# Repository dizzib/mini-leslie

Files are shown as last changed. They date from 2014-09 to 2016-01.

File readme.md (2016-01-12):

# Mini-Leslie

To aim is to reproduce the behaviour of a traditional [Leslie cabinet][Leslie]
but in a much smaller space.

## Components

* [Brushed DC motor controller](./brushed-dc-motor)
* [Upper rotor and speaker](./upper-rotor)
* [Footswitch box](./footswitch)
* [Crossover (optional)](./crossover)

## License

[MIT](./LICENSE)

[Leslie]: https://en.wikipedia.org/wiki/Leslie_speaker

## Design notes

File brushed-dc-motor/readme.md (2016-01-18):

# Brushed DC motor controller

## Parts

* Arduino Nano (or similar)
* L298N motor driver board
* 24v/120w scooter DC motor (not recommended -- see [issue #1](https://github.com/dizzib/mini-leslie/issues/1))
* small breadboard
* jumper wires
* 1kOhm resistor x 2
* 6.35mm jack

## Circuit diagram

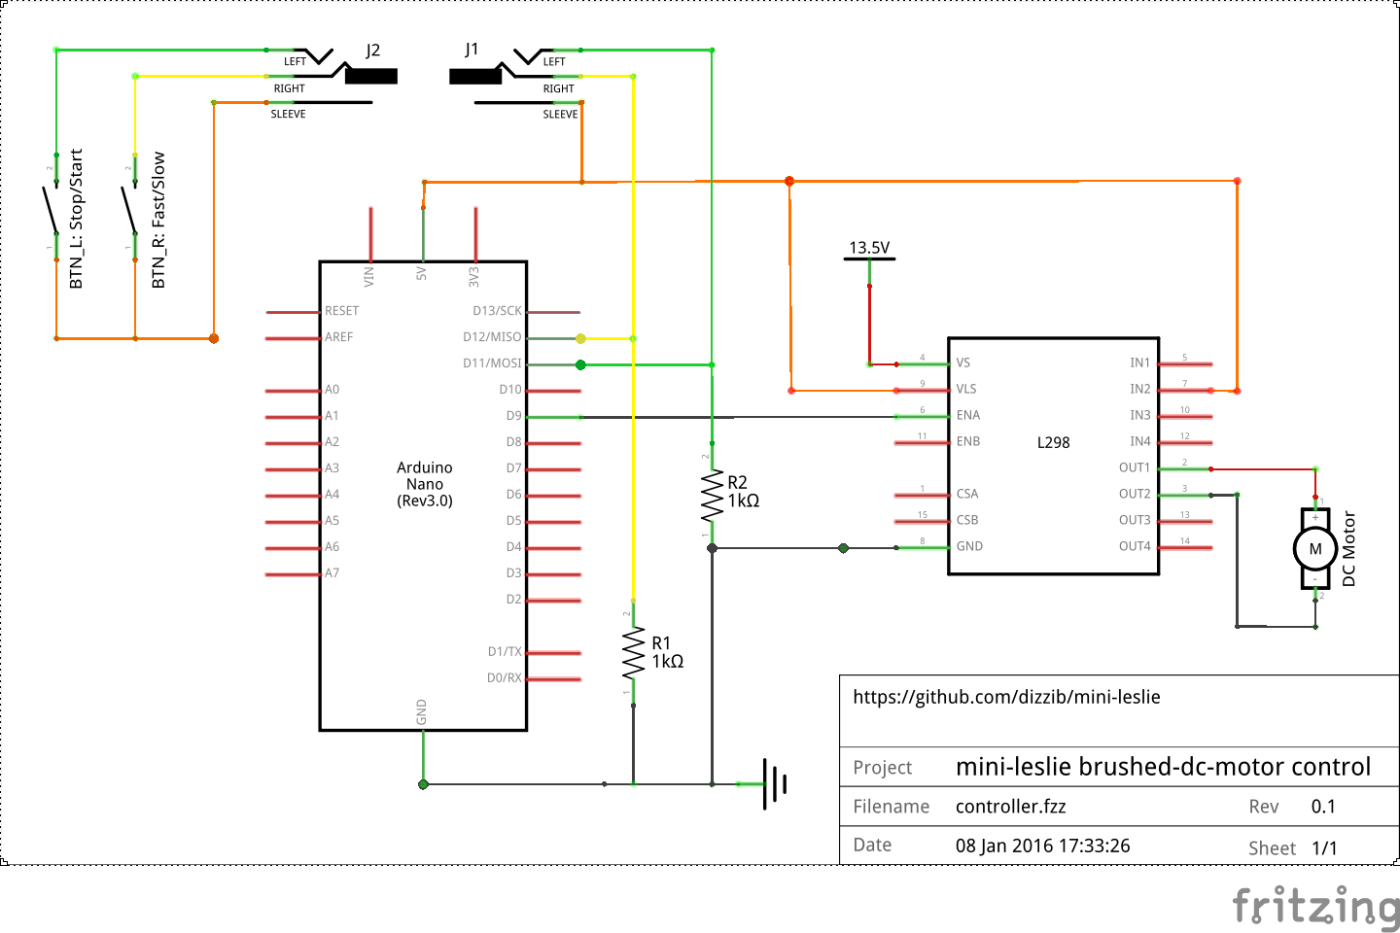
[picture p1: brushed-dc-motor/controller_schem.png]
schematic


## Notes

I'm using a 60-watt 5-amp switching power supply whose voltage options include 9/12/13.5/15v and
I've discovered 13.5v works best but YMMV.

This setup draws less than 20 watts at high speed, so I'd think both the motor
and power supply could be downsized to reduce noise and vibration.

## Pictures

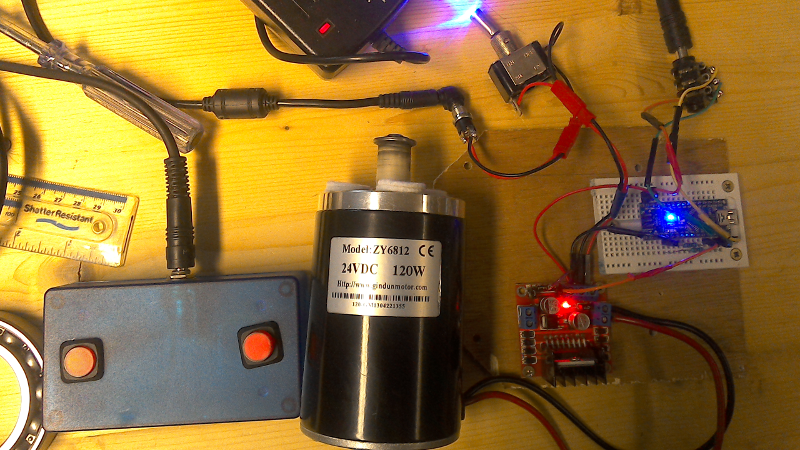
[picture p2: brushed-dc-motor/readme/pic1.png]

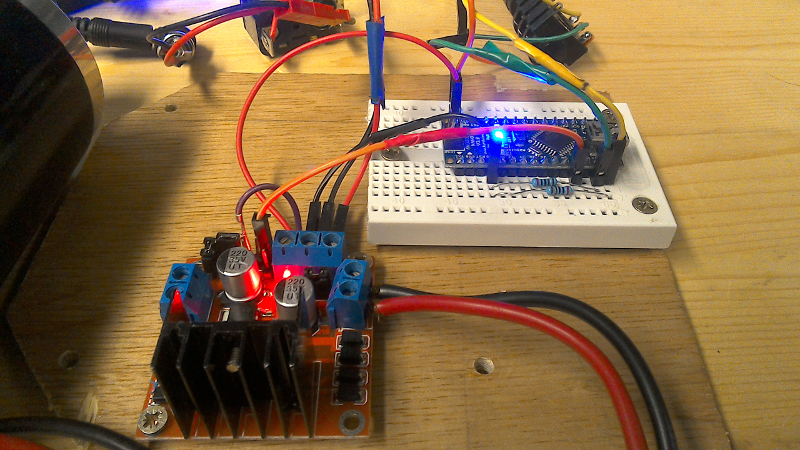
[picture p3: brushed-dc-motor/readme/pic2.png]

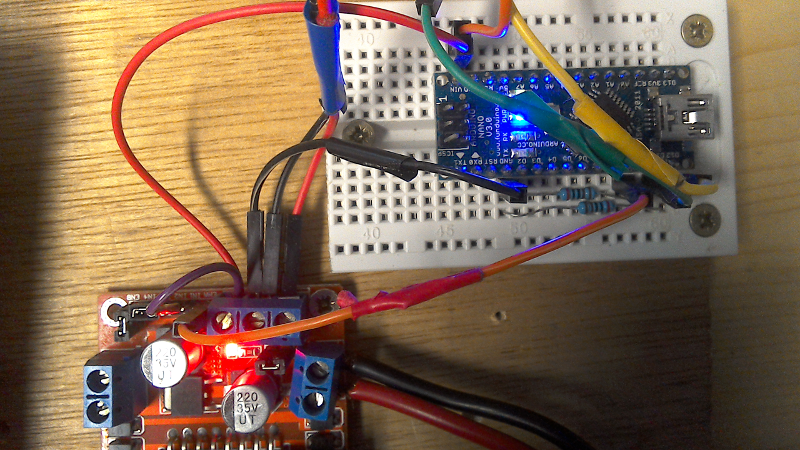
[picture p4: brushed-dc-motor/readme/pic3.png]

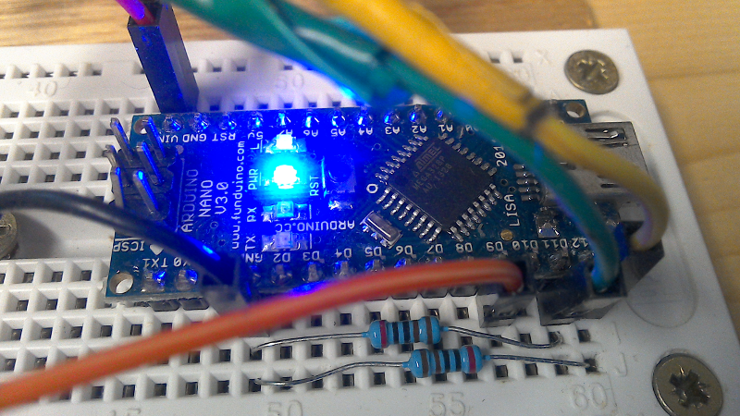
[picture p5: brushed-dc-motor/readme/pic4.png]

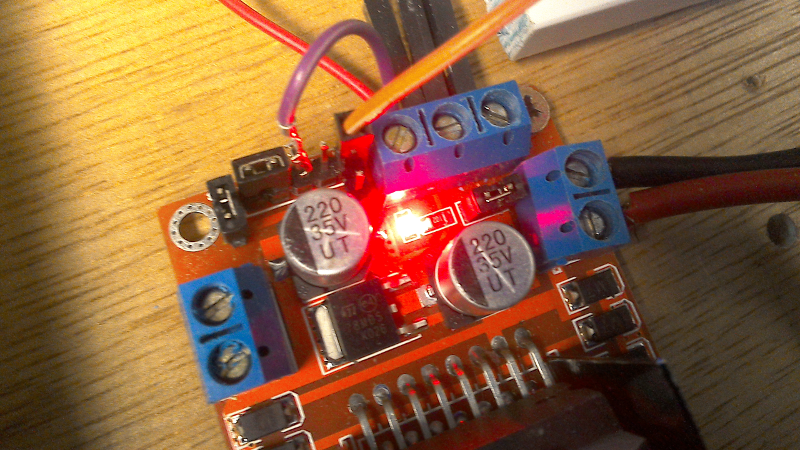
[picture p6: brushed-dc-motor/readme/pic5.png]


## Videos

[Arduino + Motor Test](https://www.youtube.com/watch?v=1-SFwXpB4cE)

[Hammond M3 Demo](https://www.youtube.com/watch?v=sb72E83Was0)

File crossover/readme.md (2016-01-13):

# Mini Crossover

Whereas an original Leslie 122 drives two 16-ohm speakers, this mini crossover is
designed to drive two 8-ohm speakers.

This is a accomplished by doubling the original capacitor values (7.8uF, 12.5uF)
and halving the original inductor values (3.2mH, 5.2mH).

## Parts

* small box 17cm x 9cm x 5.5cm
* 6.35mm jack x 3 (1 in, 2 outs)
* 15.6uF capacitor
* 25uF capacitor
* 1.6mH inductor
* 2.6mH inductor

## Circuit diagram

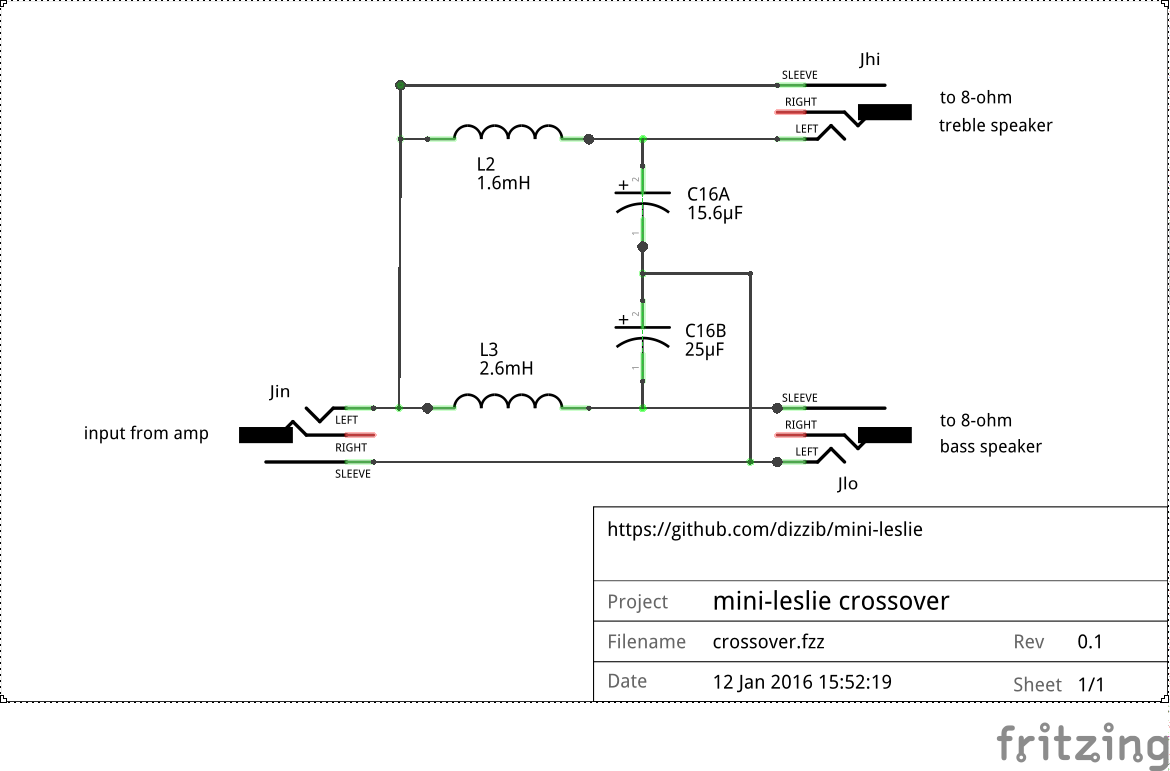
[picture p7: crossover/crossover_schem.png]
schematic


## Modifications

Since my bass speaker is 4 ohms and not 8 ohms, I took the liberty of adding a
~4 ohm resistor to the bass output (the white square ceramic resistor).

## Pics

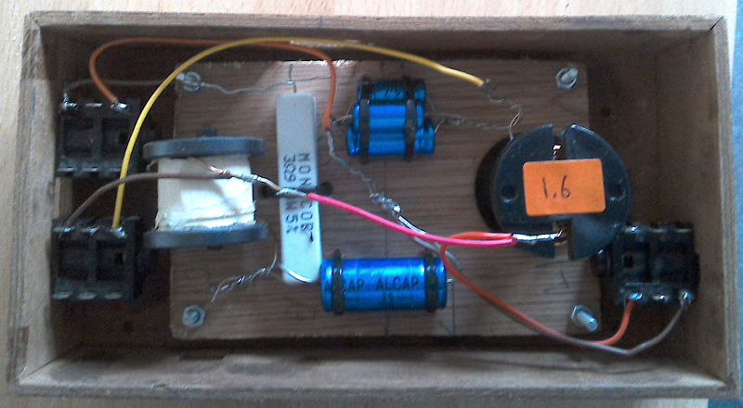
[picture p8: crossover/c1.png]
internal top view


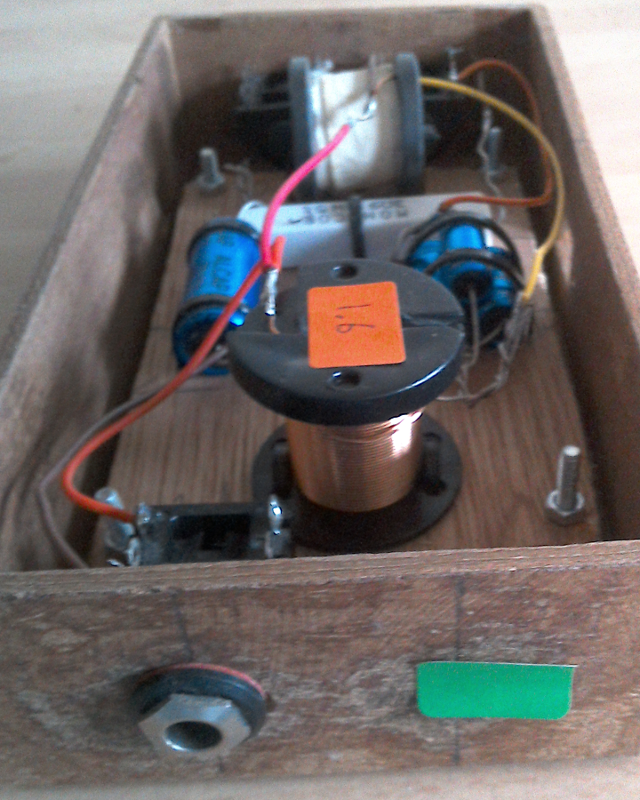
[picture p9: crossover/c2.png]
internal side view in


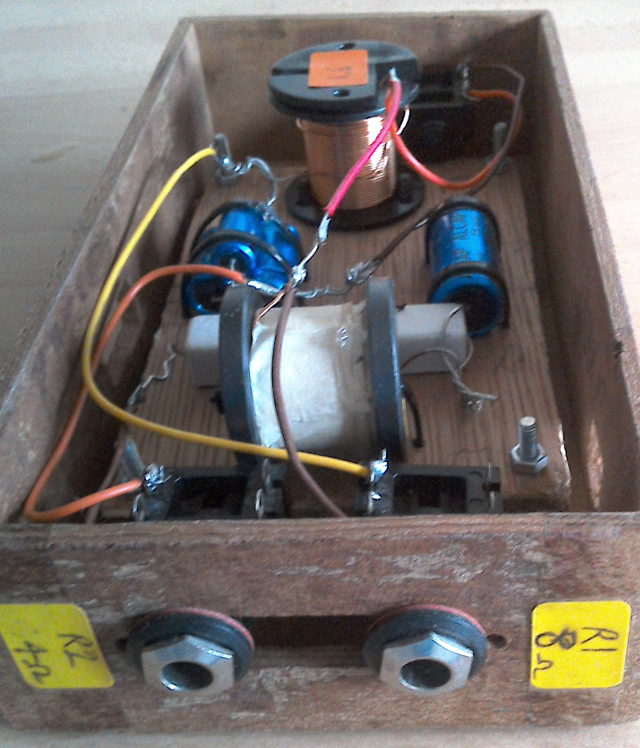
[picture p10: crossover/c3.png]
internal side view outs


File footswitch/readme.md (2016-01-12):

# Footswitch

This is a hastily thrown together component designed for gentle use in my home studio.
I'm sure you could do much better :)

## Parts

* small box 11cm x 5cm x 2.5cm
* latching on/off push buttons x 2
* 6.35mm jack

## Pics

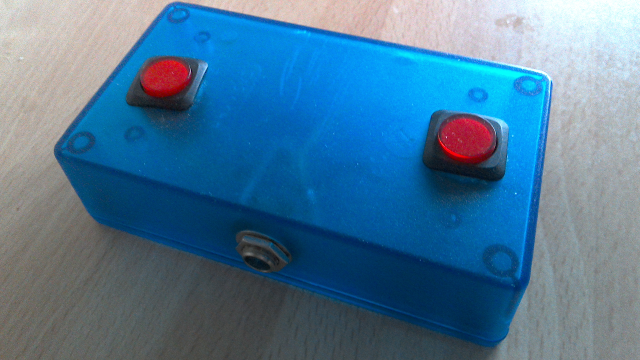
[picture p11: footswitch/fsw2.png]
exterior


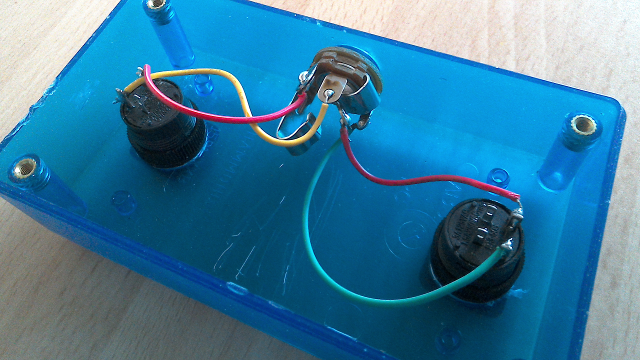
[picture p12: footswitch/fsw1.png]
internals


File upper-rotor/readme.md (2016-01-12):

# Upper rotor and speaker

TODO

## Parts

* metal 7-inch record box 20cm x 20cm x 20cm
* plumbing pipe 50mm outer diameter (OD)
* 50mm OD pipe joint of angle 112.5 deg
* bearing 50mm inner 80mm outer
* plastic funnel
* rubber belt 3mm diameter
* counterweight bolt M8x50mm
* counterweight slabs and M10 washers
* 50mm M4 screws
* speaker
* toggle switch for power
* DC power socket
* 6.35mm jack for speaker
* 6.35mm jack for footswitch

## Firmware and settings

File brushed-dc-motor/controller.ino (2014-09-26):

const int PIN_ENA    = 9;
const int PIN_BTN_L  = 11;
const int PIN_BTN_R  = 12;
const int RAMP_DELAY = 30; // ms

// assumes 13.5V input
enum STATE { STOP = 0, SLOW = 146, FAST = 235 };

void setup() {
  Serial.begin(9600);

  pinMode(PIN_ENA,  OUTPUT);
  pinMode(PIN_BTN_L, INPUT);
  pinMode(PIN_BTN_R, INPUT);

  // increase pwm width from 490Hz to 30Khz to stop motor buzz
  // http://forum.arduino.cc/index.php/topic,16612.0.html#4
  // MAY HAVE SIDE EFFECTS!
  TCCR1B = TCCR1B & 0b11111000 | 0x01;
}

void loop() {
  static int state = STOP;
  static int speed = STOP;

  setState(&state);
  setSpeed(&state, &speed);
}

void setState(int *state) {
  bool btn_l = digitalRead(PIN_BTN_L);
  bool btn_r = digitalRead(PIN_BTN_R);
  *state = btn_l ? (btn_r ? FAST : SLOW) : STOP;
}

void setSpeed(int *state, int *speed) {
  const int KICKSTART = 5;
  if (*speed > SLOW) switch (*state) {
    case FAST:
      if (*speed < FAST) (*speed)++;
      break;
    default:
      if (*speed > SLOW) (*speed)--;
      break;
  }
  else switch (*state) {
    case FAST:
      *speed = SLOW + 1;
      break;
    case SLOW:
      *speed = SLOW + ((*speed == STOP) ? KICKSTART : 0);
      break;
    case STOP:
      *speed = STOP;
      break;
  }
  Serial.println(*speed);
  analogWrite(PIN_ENA, *speed);
  delay(RAMP_DELAY);
}

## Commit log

2016-01-08 add schematic
2016-01-08 add link to schematic
2016-01-12 embed schematic
2016-01-12 reorg, add footswitch and upper-rotor
    [controller.fzz]
2016-01-12 amend revision to 0.1
    [controller.fzz]
2016-01-12 schematic wip
    [crossover.fzz]
2016-01-13 add crossover schematic
    [crossover.fzz]
